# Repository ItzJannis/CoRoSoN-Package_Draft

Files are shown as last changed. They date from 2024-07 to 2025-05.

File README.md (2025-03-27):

# CoRoSoN-Package Draft
>**Co**|mponents for \
>**Ro**|bocupJunior \
>**So**|ccer \
> **N**|ewcomers \
> Project: [CoRoSoN-Kit](https://github.com/CoRoSoN-Kit/CoRoSoN-Kit) \
> Competition: [RoboCup](https://www.robocup.org) \
> Author: [BohleBots](https://www.bohlebots.de)

# Description
This project offers a draft version to the official [CoRoSoN-Kit](https://github.com/CoRoSoN-Kit/CoRoSoN-Kit) to provide the fundamental building blocks for a fully functional robot participating in the Soccer Junior division of the [RoboCup](https://www.robocup.org). \
The purpose is to allow for an newcomer friendly entry to the competition by wrapping the essential functions with easy to use APIs. Board designs are designed to be rebuild easily and affordable. \
\
Feel free to reach out to us for questions, feedback, suggestions or constructive critism! \
See you in the competition!

## Disclaimer
The software and the hardware designs are developed to the best of our knowledge to serve the intented purpose, but may still contain faults. Our software and hardware are provided "as is" and do not provide any warranty. The risk of using it and all neccessary servicing, repair and correction as well as their cost is with you.

# Makefile
Using the Arduino IDE or arduino-cli requires all source for a .ino sketch to be inside the sketch folder or inside the libaries directory of the Arduino installation. \
Therefore source files inside Software/Shared or Software/Peripheral, that are not located directly next to a .ino sketch, cause problems. \
To allow for easy compatibility of this project with Arduino the Makefile was created. \
It automates the generation of valid Arduino sketch folders, such that they can be opened in the Arduino IDE or used with arduino-cli. \
\
The Makefile does not require all source files to be inside the sketch folder, but it requires SketchName.ino to be located inside Software/SketchName/.
\
Run `make` inside the home directory of this repo to see all the options.

# Software
## Requirements
1. [Arduino](https://www.arduino.cc/)
2. [Espressif ESP32 Board Information](https://github.com/espressif/arduino-esp32)
3. [elapsedMillis](https://github.com/pfeerick/elapsedMillis/wiki)
4. [PixyI2C](https://pixycam.com/downloads-pixy1/)
5. [Pixy2I2C](https://pixycam.com/downloads-pixy2/)

## Shared
Software that is not build for a specific board but is shared across different board's software.

### CoRoSoN_Util
Providing usefull utility definitions for error handling, initializing data and better debugging. \
The `enum ERROR_CODE` provides bitflags for uniform error handling while `DEBUG_PRINT(Variable)`, `DEBUG_ERRORS(Errors)` and `DEBUG_BLOCK(Message, NumMillis)` provide easier debugging via the serial connection and the `MIN(X,Y)`, `MAX(X,Y)`, `ABS(X)`, `ARRAY_LENGTH(Arr)`, `ZEROMEM(Obj)` provide function-like macros to handle data without tedious reimplementation of often used functionalities.

### CoRoSoN_I2C
Providing a simpler, more beginner friendly interface to work with the I2C bus system used in this project. \
`I2C_Init()`, `I2C_TestConnection()`, `I2C_Write()` and `I2C_ReadBlocking()` provide all the functionality a newcomer robot for the competition needs. \
**Attention**: \
`I2C_ReadBlocking()` waits for the answers and is therefore **blocking** the execution of the program. \
Make sure that NumBytes equals the length of the passed byte array!

### CoRoSoN_Vector
Providing `class Vector` to easily compute vectorial calculations with functions and operator overloading.

### CoRoSoN_Config
This file defines the hardware configuration (namely the pins) for the software.

## Main
Software that is supposed to be used on the mainboard.
### CoRoSoN_Main
The definitions of `enum COLOR`, `enum SIDE`, `enum I2C_ADD_BTNLED_MODULE`, `enum MOTOR` and `enum DIRECTION` are used to firstly make software better readable for newcomers and secondly somehow restrict inputs to reduce buggy behavior due to occasionally wrong inputs. \
`CoRoSoN_Init()`, `CoRoSoN_SetLEDColor()`, `CoRoSoN_ButtonIsPressed()` and `CoRoSoN_SetMotor()` provide a beginner friendly API to setting the mainboard up in the `setup()` of an arduino program as well as reading and writing the mainboards pins.

## Peripheral
Software that is supposed to be used on the mainboard to make use of the peripheral devices.
### CoRoSoN_Eeprom
Providing an interface to the ESP32's eeprom which is easy to use.\
The eeprom is very usefull to save backup data about the current program state (i.e. the robot is enabled to drive) in case of a shutdown or a reset for whatever reason.\
The `struct EEPROM_DATA` can be filled with whatever you want to read / write from the eeprom.
`EEPROM_Init()`, `EEPROM_Read()` and `EEPROM_Write()` provide an easy interface that only deals with instances of `EEPROM_DATA`.

### CoRoSoN_Pixy
Providing `class Pixy` with its `Update()`, `GoalSeen()`, `OwnGoalSeen()`, `GoalDirection()` and `OwnGoalDirection()` to make use of the Pixy camera for locating the two goals on the playing field. \
In `CoRoSoN_Pixy.h` set `PIXY_VERSION` to 1 or 2 according to the version of the Pixy cam in use. \
For the directions: <0 represents left, >0 represents right

### CoRoSoN_IR-Ring
Providing `class IRRing` with its `Update()`, `BallSeen()`, `BallDirection()` and `BallDistance()` to make use of the infrared sensor ring with the firmware running on it (also provided).
For the directions: <0 represents left, >0 represents right, 0 represents front, -32 represents no ball seen
For the distance: 1...32 represents closest...furthest, 0 represents no ball seen

## IR
Software that is supposed to be used on the infrared sensor ring.
### Firmware_IR-Ring
Providing the firmware that is designed to be loaded onto the infrared sensor ring and making it ready to be used in a plug-and-play manner. \
#### Software Process / Algorithm
1. Read all physical signals
2. Remove minimum value from all sensor values (ensuring at least one is 0)
3. Use exponential moving average (EMA) for each sensor - the lower `EMA_ALPHA_PERCENTAGE`, the more the values are smoothed
4. Gaussian blur on each sensors value with its 2 neighbouring values - `BLUR_ORIGINAL_VALUE_WEIGHT_PERCENTAGE` defines the weight the middle sensor gets
5. Exaggerate differences by squaring percentage of maximum value for each sensor
6. Expand values to higher resolution by using cubic interpolation
7. Giving the sensors close to the last output direction a boost of up to 5% of their current value, to reduce fluctuations
8. Find highest value
9. Exaggerate differences by squaring percentage of maximum value for each sensor
10. Vector addition around highest value for more precise direction - `VECTOR_ADDITION_SENSOR_COUNT` defines the number of vectors involved
11. Determine distance by numeric integration
12. Compute final direction and distance with running median - `RUNNING_MEDIAN_DIRECTION_LENGTH` and `RUNNING_MEDIAN_DISTANCE_LENGTH` define the history length for the running medians

# Hardware
## Main
Contains the [KiCad](https://www.kicad.org/download/) project of the Main PCB. 

## IR-Ring
Contains the [KiCad](https://www.kicad.org/download/) project of the IR-Ring PCB. 

## 3D_Prints
Contains all the 3D printable designs as .stl files.

### CasterBall
Spherical third ground contact point to prevent the robot from falling over due to having only 2 wheels.
### Chassis_TopPlate
The main plate enclosing the chassis, also including part of the machanism to hold the battery pack.
### Dribbler_Enclosure
Holds the dribbling unit (motor and rotating silicone shell).
### Dribbler_Enclosure_EndCap
The end cap to close the enclosure of the dribbling unit.
### Dribbler_Mounting
Add-On to the top plate to mount the dribbling unit and support the IR-Ring up on top.
### Dribbler_Mounting_short
Shorter version of Dribbler_Mounting.stl in terms of height.
### Dribbler_ShellCoupling
Coupling adapter to connect the rotating shell to the motor axis.
### Dribbler_SiliconeRoller
Rotating shell of the dribbling unit, supposed to be covered with silicone.
### IR-Ring_Cover
Covers the IR-Ring PCB to reduce external ambient noise for the sensors.
### IR-Ring_Cover_Counterpart
Counterpart for the IR-Ring cover such that it is properly fixated.
### Main_Frame
Mounting frame for the Main PCB.
### Pixy_Mounting
Mounting frame for pixy camera.
### WheelCoupling
Coupling adapter to connect the wheels to the motor axis.

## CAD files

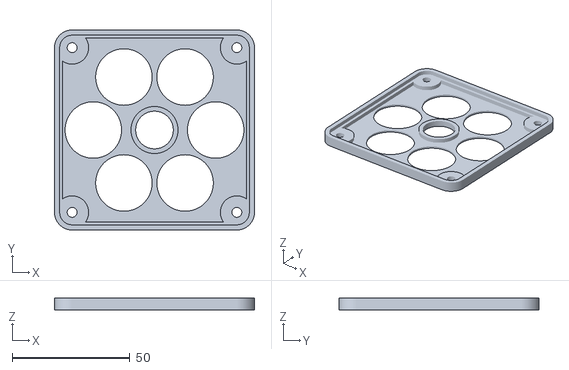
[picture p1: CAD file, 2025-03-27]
Hardware/3D_Prints/Main_Frame.stl
85.0 x 85.0 x 5.00

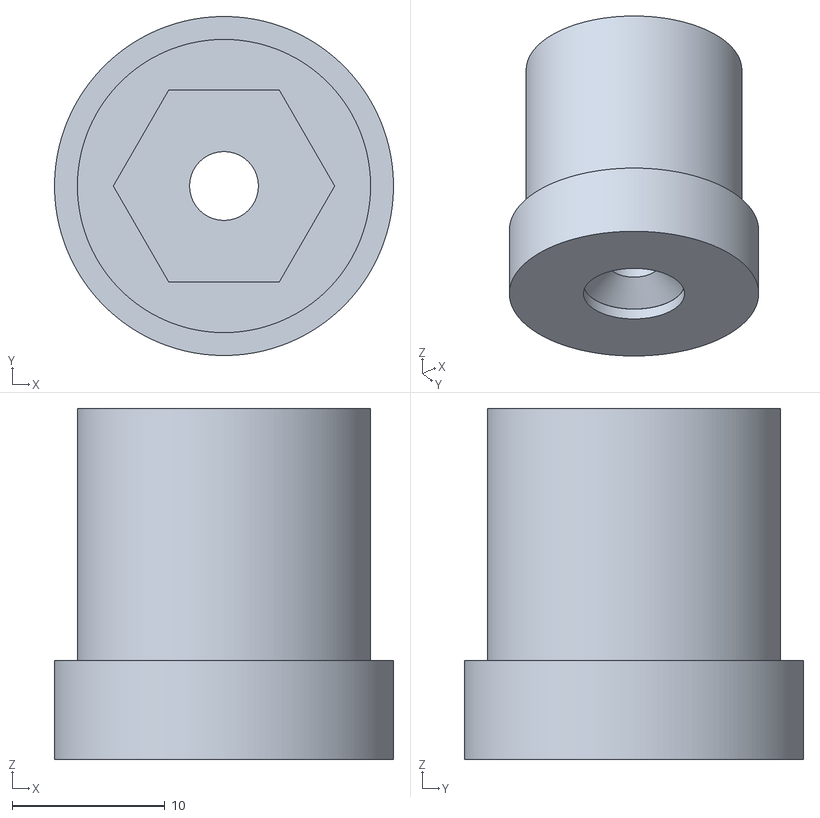
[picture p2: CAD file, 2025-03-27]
Hardware/3D_Prints/WheelCoupling.stl
22.2 x 22.2 x 23.0

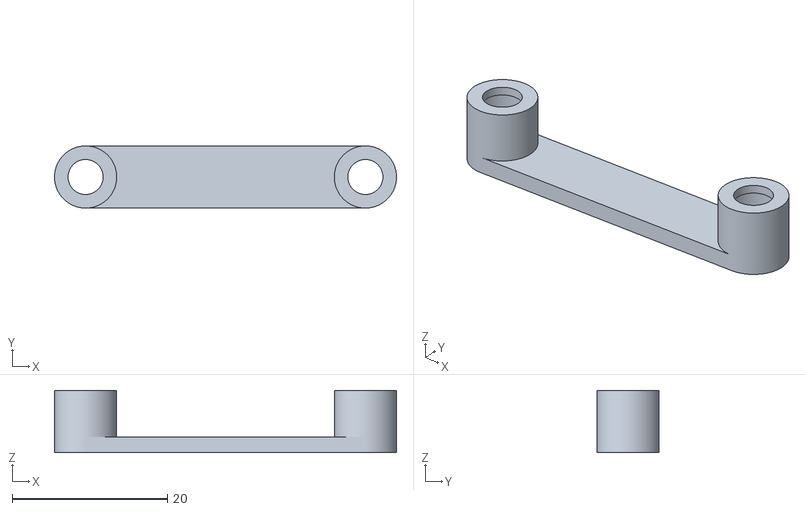
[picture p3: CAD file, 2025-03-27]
Hardware/3D_Prints/IR-Ring_Cover_Counterpart.stl
44.0 x 8.00 x 8.00

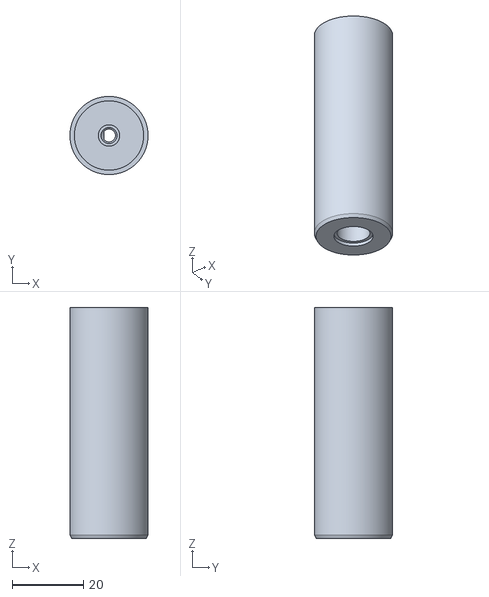
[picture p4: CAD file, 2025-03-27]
Hardware/3D_Prints/Dribbler_SiliconeRoller.stl
22.0 x 22.0 x 65.0

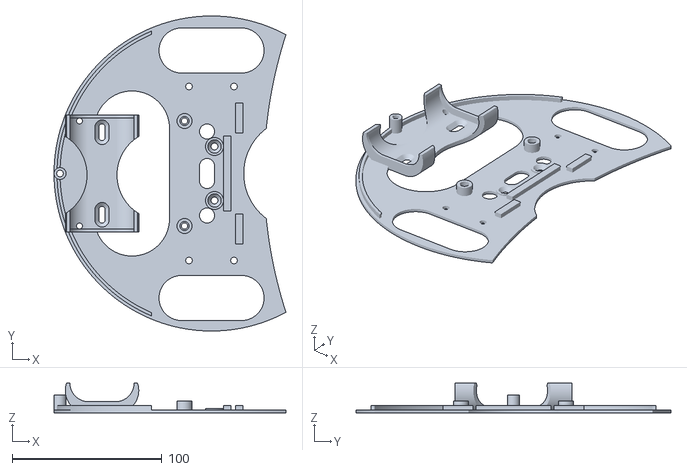
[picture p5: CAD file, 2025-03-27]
Hardware/3D_Prints/Chassis_TopPlate.stl
154.6 x 210.0 x 20.0

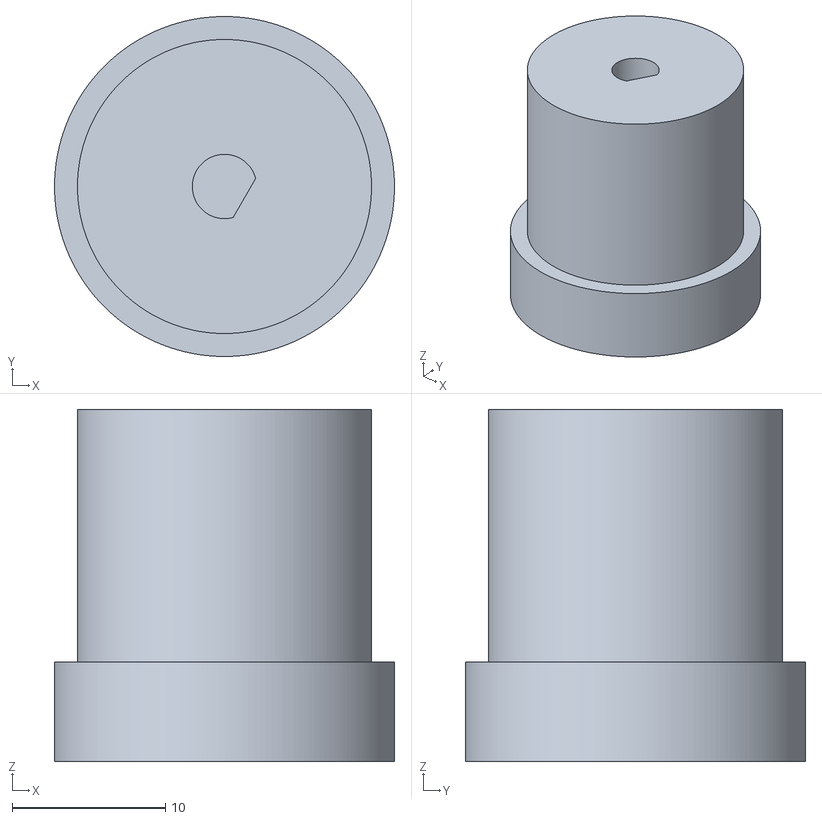
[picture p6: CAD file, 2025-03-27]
Hardware/3D_Prints/Dribbler_ShellCoupling.stl
22.2 x 22.2 x 23.0

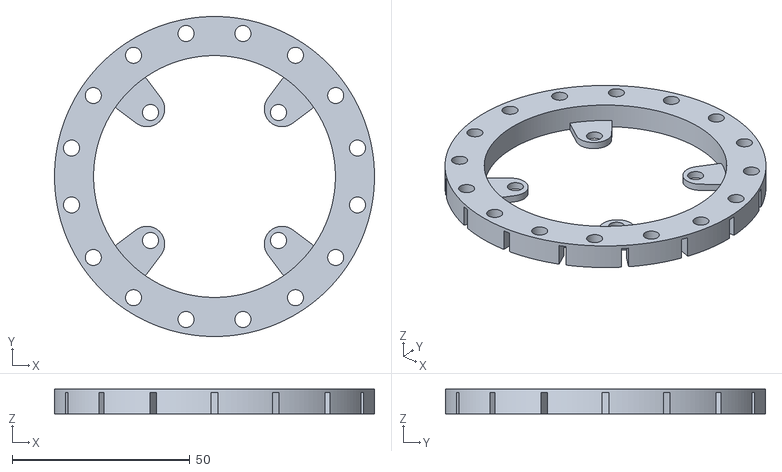
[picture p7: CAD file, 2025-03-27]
Hardware/3D_Prints/IR-Ring_Cover.stl
90.0 x 90.0 x 7.00

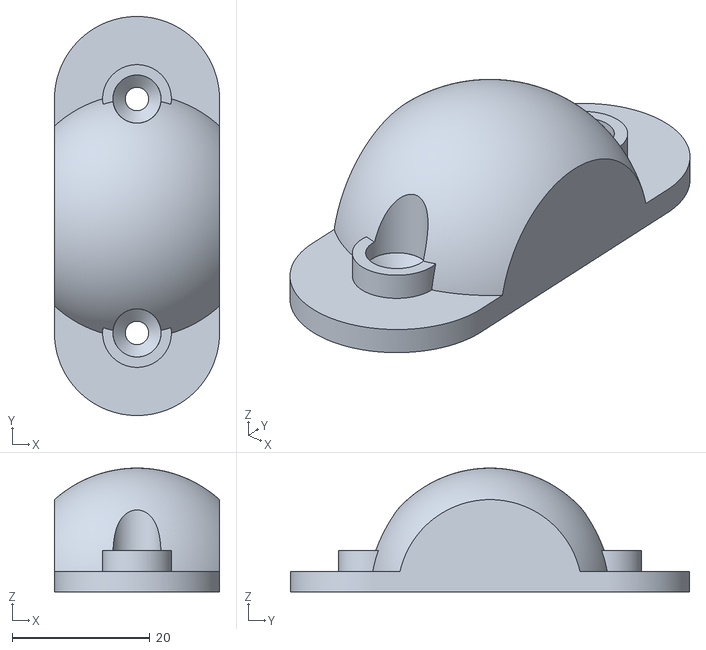
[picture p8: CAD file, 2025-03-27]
Hardware/3D_Prints/CasterBall.stl
24.0 x 58.0 x 18.0

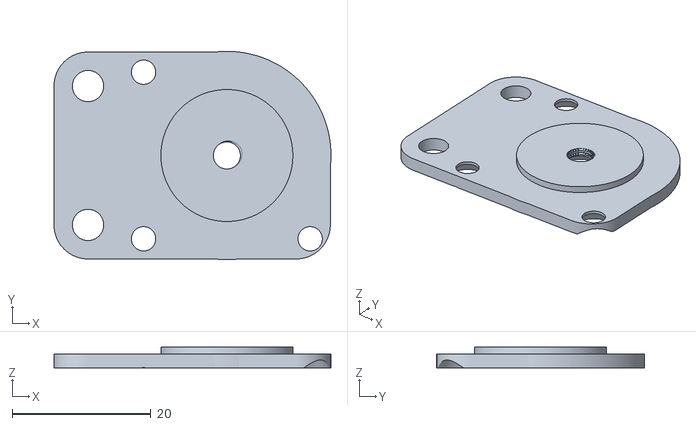
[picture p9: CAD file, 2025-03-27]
Hardware/3D_Prints/Dribbler_Enclosure_EndCap.stl
39.9 x 30.0 x 3.00

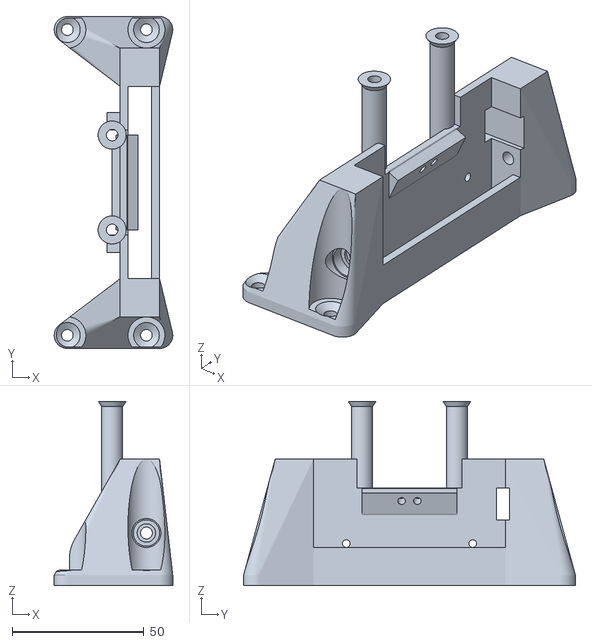
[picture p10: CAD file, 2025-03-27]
Hardware/3D_Prints/Dribbler_Mounting_short.stl
45.0 x 126.0 x 70.0

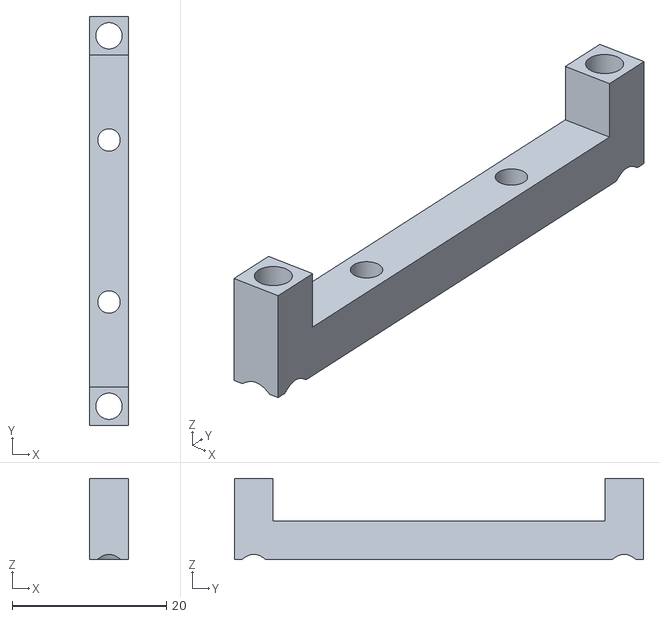
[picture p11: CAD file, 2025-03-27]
Hardware/3D_Prints/Pixy_Mounting.stl
5.00 x 53.0 x 10.5

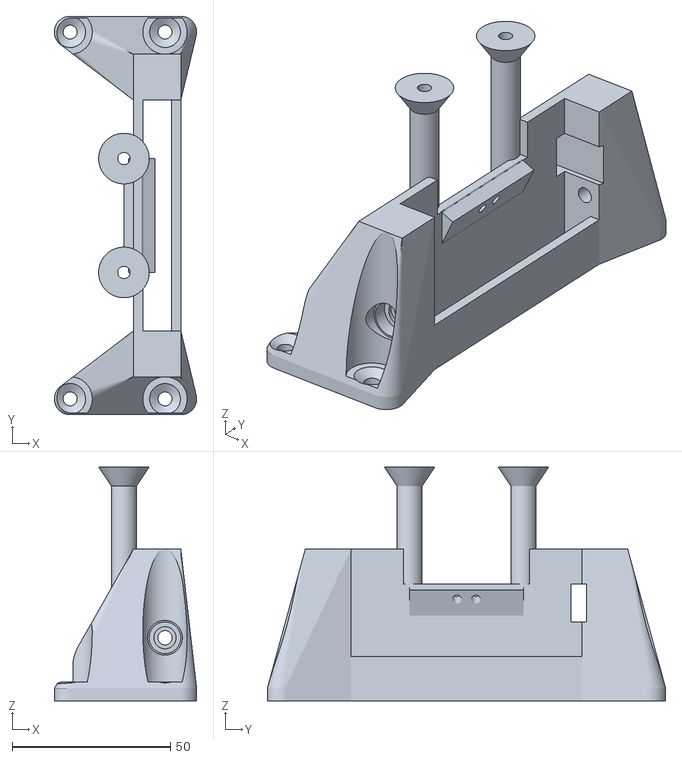
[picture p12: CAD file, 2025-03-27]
Hardware/3D_Prints/Dribbler_Mounting.stl
45.0 x 126.0 x 74.0

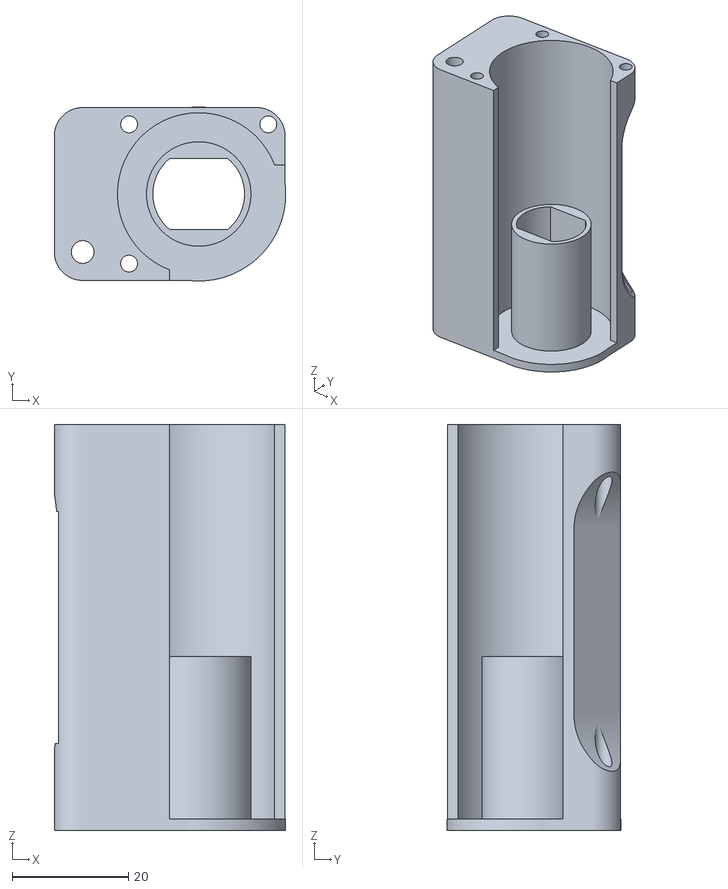
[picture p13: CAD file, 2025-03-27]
Hardware/3D_Prints/Dribbler_Enclosure.stl
39.9 x 30.0 x 70.0

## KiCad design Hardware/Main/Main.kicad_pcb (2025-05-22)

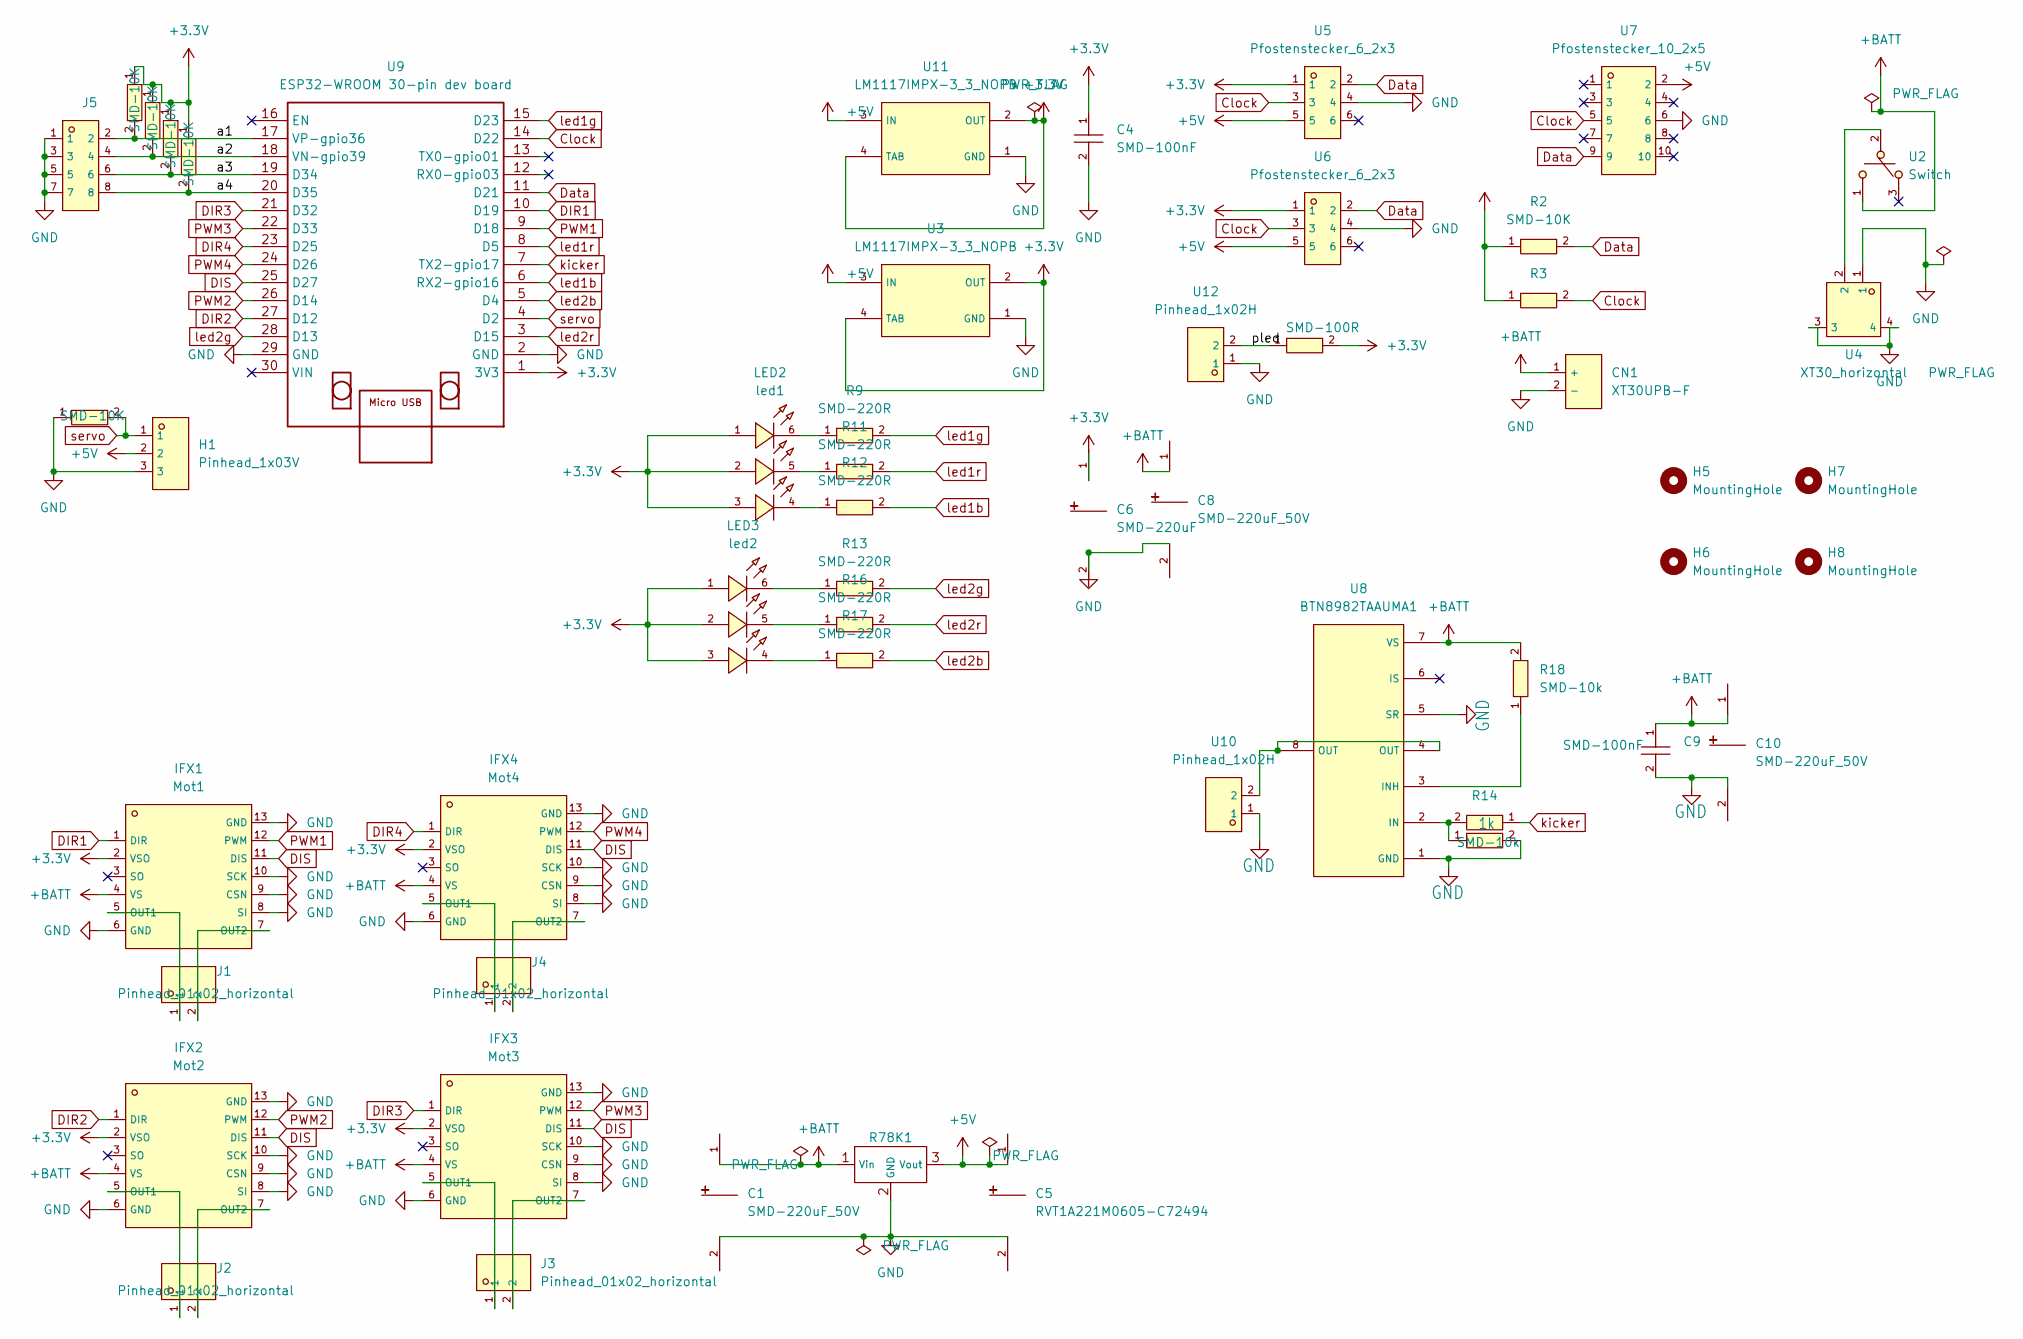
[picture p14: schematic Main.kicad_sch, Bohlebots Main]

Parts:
C1, C8, C10: SMD-220uF_50V; CAP-SMD_BD10.0-L10.3-W10.3-LS11.3-FD; LCSC C125977
C4, C9: SMD-100nF; C0603; LCSC C30926
C5: RVT1A221M0605-C72494; CAP-SMD_BD10.0-L10.3-W10.3-LS11.3-FD; LCSC C125977
C6: SMD-220uF; CAP-SMD_BD10.0-L10.3-W10.3-LS11.3-FD; LCSC C125977
CN1: XT30UPB-F; CONN-TH_XT30UPB-F; LCSC C108769
H1: Pinhead_1x03V; HDR-TH_3P-P2.54-V-M-1; LCSC C7501261
H5, H6, H7, H8: MountingHole; MountingHole_4.3mm_M4
IFX1: Mot1; SO-12_L6.4-W7.5-P1.00-LS10.3-BL-EP; LCSC C112633
IFX2: Mot2; SO-12_L6.4-W7.5-P1.00-LS10.3-BL-EP; LCSC C112633
IFX3: Mot3; SO-12_L6.4-W7.5-P1.00-LS10.3-BL-EP; LCSC C112633
IFX4: Mot4; SO-12_L6.4-W7.5-P1.00-LS10.3-BL-EP; LCSC C112633
J1, J2, J3, J4: Pinhead_01x02_horizontal; HDR-TH_2P-P2.54-H-M-W10.4; LCSC C492410
J5: Conn_02x04_Row_Letter_First; HDR-TH_8P-P2.54-H-M-R2-C4-S2.54; LCSC C706885
LED2: led1; LED-SMD_6P-L5.0-W5.0-TL_TC5050RGBF08; LCSC C784540
LED3: led2; LED-SMD_6P-L5.0-W5.0-TL_TC5050RGBF08; LCSC C784540
R2, R3, R5, R6, R7, R10, R15: SMD-10K; R0603; LCSC C25804
R8: SMD-100R; R0603; LCSC C22775
R9, R11, R12, R13, R16, R17: SMD-220R; R0603; LCSC C217883
R14, R18: SMD-10k; R0603; LCSC C25804
R23: 1k; R0603; LCSC C22548
R78K1: R785K
U2: Switch; SW-TH_MT-0-103-A101-M200-RS; LCSC C1788498
U3, U11: LM1117IMPX-3_3_NOPB; SOT-223_L6.5-W3.5-P2.30-LS7.0-BR; LCSC C23984
U4: XT30_horizontal; CONN-TH_XT30PW-M; LCSC C431092
U5, U6: Pfostenstecker_6_2x3; HDR-TH_6P-P2.54-V-F-R2-C3-S2.54-4; LCSC C5372863
U7: Pfostenstecker_10_2x5; HDR-TH_10P-P2.54-V-F-R2-C5-S2.54-5; LCSC C5372865
U8: BTN8982TAAUMA1; TO-263-7_L10.2-W10.4-P1.27-LS14.4-TL; LCSC C74175
U9: ESP32-WROOM 30-pin dev board; MODULE_ESP32_DEVKIT_V1
U10, U12: Pinhead_1x02H; HDR-TH_2P-P2.54-H-M-W10.4; LCSC C492410

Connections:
+3.3V: C4.1, C6.1, IFX1.2 (VSO), IFX2.2 (VSO), IFX3.2 (VSO), IFX4.2 (VSO), LED2.1 (+), LED2.2 (+), LED2.3 (+), LED3.1 (+), LED3.2 (+), LED3.3 (+), R2.1, R3.1, R5.1, R6.1, R7.1, R8.2, R10.1, U3.2 (OUT), U3.4 (TAB), U5.1, U6.1, U9.1 (3V3), U11.2 (OUT), U11.4 (TAB)
+5V: C5.1, H1.2, R78K1.3 (Vout), U3.3 (IN), U5.5, U6.5, U7.2, U11.3 (IN)
+BATT: C1.1, C8.1, C9.1, C10.1, CN1.1 (+), IFX1.4 (VS), IFX2.4 (VS), IFX3.4 (VS), IFX4.4 (VS), R18.2, R78K1.1 (Vin), U2.1, U8.7 (VS)
/a1: J5.2, R5.2, U9.17 (VP-gpio36)
/a2: J5.4, R6.2, U9.18 (VN-gpio39)
/a3: J5.6, R7.2, U9.19 (D34)
/a4: J5.8, R10.2, U9.20 (D35)
/pled: R8.1, U12.2
Clock: R3.2, U5.3, U6.3, U7.5, U9.14 (D22)
DIR1: IFX1.1 (DIR), U9.10 (D19)
DIR2: IFX2.1 (DIR), U9.27 (D12)
DIR3: IFX3.1 (DIR), U9.21 (D32)
DIR4: IFX4.1 (DIR), U9.23 (D25)
DIS: IFX1.11 (DIS), IFX2.11 (DIS), IFX3.11 (DIS), IFX4.11 (DIS), U9.25 (D27)
Data: R2.2, U5.2, U6.2, U7.9, U9.11 (D21)
GND: C1.2, C4.2, C5.2, C6.2, C8.2, C9.2, C10.2, CN1.2 (-), H1.3, IFX1.6 (GND), IFX1.8 (SI), IFX1.9 (CSN), IFX1.10 (SCK), IFX1.13 (GND), IFX2.6 (GND), IFX2.8 (SI), IFX2.9 (CSN), IFX2.10 (SCK), IFX2.13 (GND), IFX3.6 (GND), IFX3.8 (SI), IFX3.9 (CSN), IFX3.10 (SCK), IFX3.13 (GND), IFX4.6 (GND), IFX4.8 (SI), IFX4.9 (CSN), IFX4.10 (SCK), IFX4.13 (GND), J5.1, J5.3, J5.5, J5.7, R14.2, R15.1, R78K1.2 (GND), U3.1 (GND), U4.1, U4.3, U4.4, U5.4, U6.4, U7.6, U8.1 (GND), U8.5 (SR), U9.2 (GND), U9.29 (GND), U10.1, U11.1 (GND), U12.1
unnamed: IFX1.5 (OUT1), J1.1
unnamed: IFX1.7 (OUT2), J1.2
unnamed: IFX2.5 (OUT1), J2.1
unnamed: IFX2.7 (OUT2), J2.2
unnamed: IFX3.5 (OUT1), J3.1
unnamed: IFX3.7 (OUT2), J3.2
unnamed: IFX4.5 (OUT1), J4.1
unnamed: IFX4.7 (OUT2), J4.2
unnamed: LED2.4 (-), R12.1
unnamed: LED2.5 (-), R11.1
unnamed: LED2.6 (-), R9.1
unnamed: LED3.4 (-), R17.1
unnamed: LED3.5 (-), R16.1
unnamed: LED3.6 (-), R13.1
unnamed: U2.2, U4.2
unnamed: R14.1, R23.2, U8.2 (IN)
unnamed: R18.1, U8.3 (INH)
unnamed: U8.4 (OUT), U8.8 (OUT), U10.2
PWM1: IFX1.12 (PWM), U9.9 (D18)
PWM2: IFX2.12 (PWM), U9.26 (D14)
PWM3: IFX3.12 (PWM), U9.22 (D33)
PWM4: IFX4.12 (PWM), U9.24 (D26)
kicker: R23.1, U9.7 (TX2-gpio17)
led1b: R12.2, U9.6 (RX2-gpio16)
led1g: R9.2, U9.15 (D23)
led1r: R11.2, U9.8 (D5)
led2b: R17.2, U9.5 (D4)
led2g: R13.2, U9.28 (D13)
led2r: R16.2, U9.3 (D15)
servo: H1.1, R15.2, U9.4 (D2)

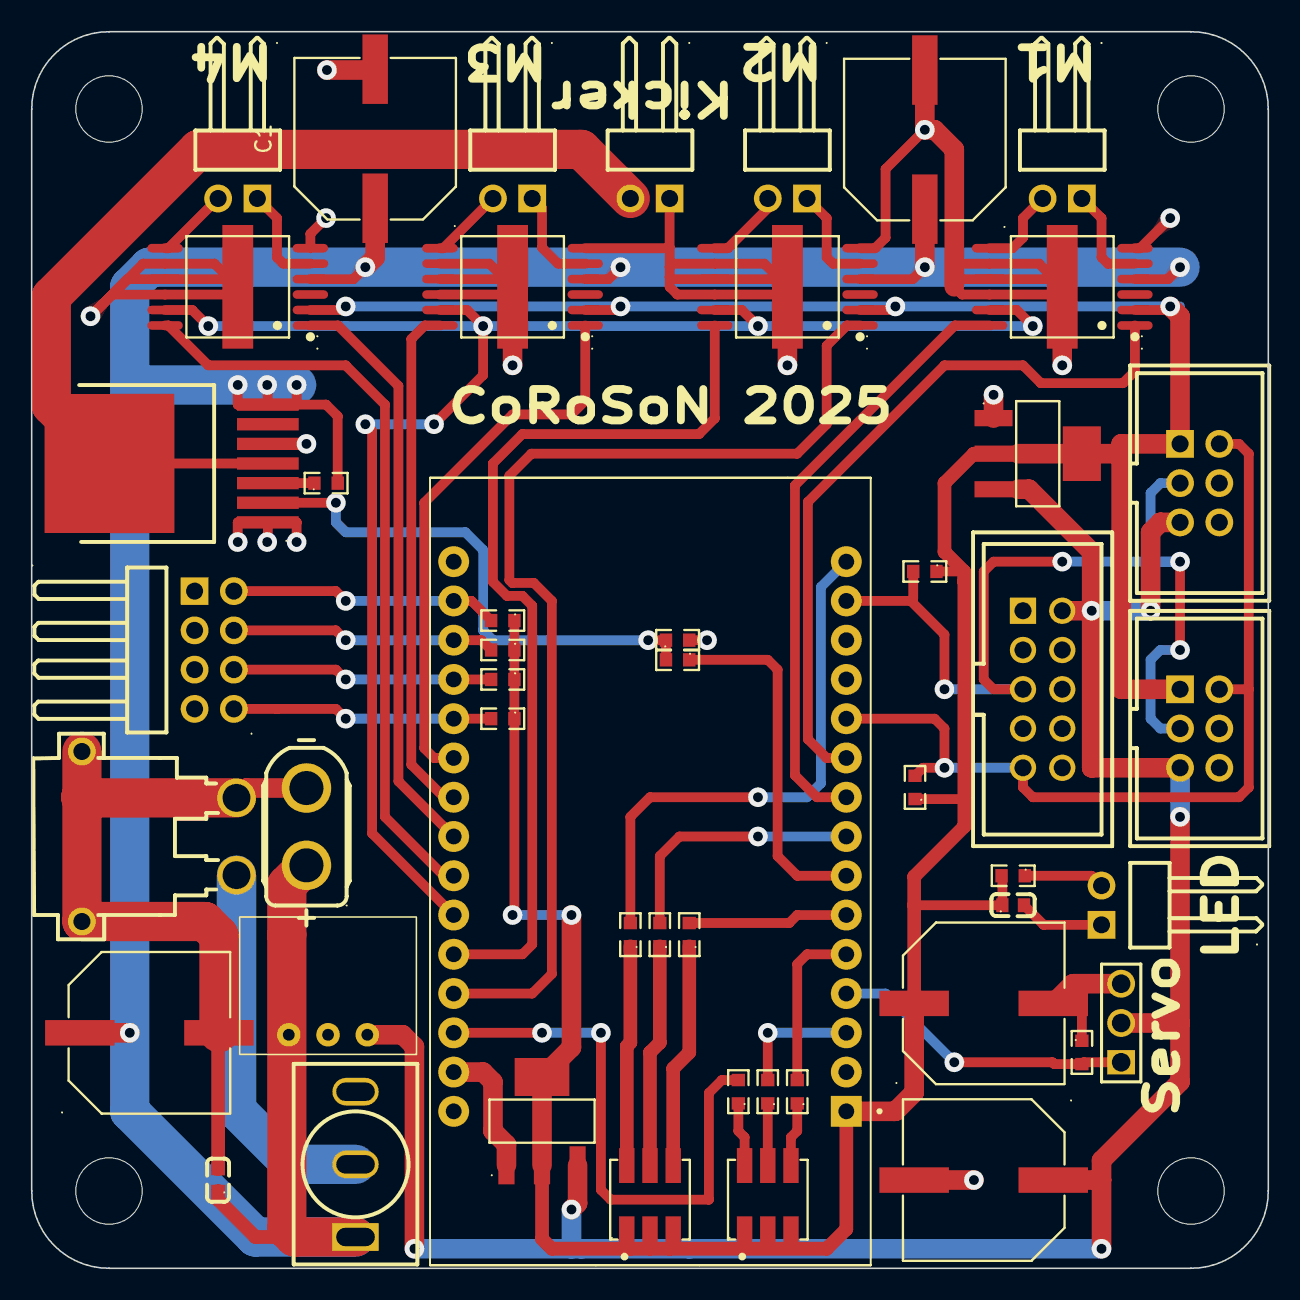
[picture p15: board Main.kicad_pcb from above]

Board: 2 copper layers, 80.0 x 80.0 mm, 53 parts (0 on the bottom side), 46 nets.

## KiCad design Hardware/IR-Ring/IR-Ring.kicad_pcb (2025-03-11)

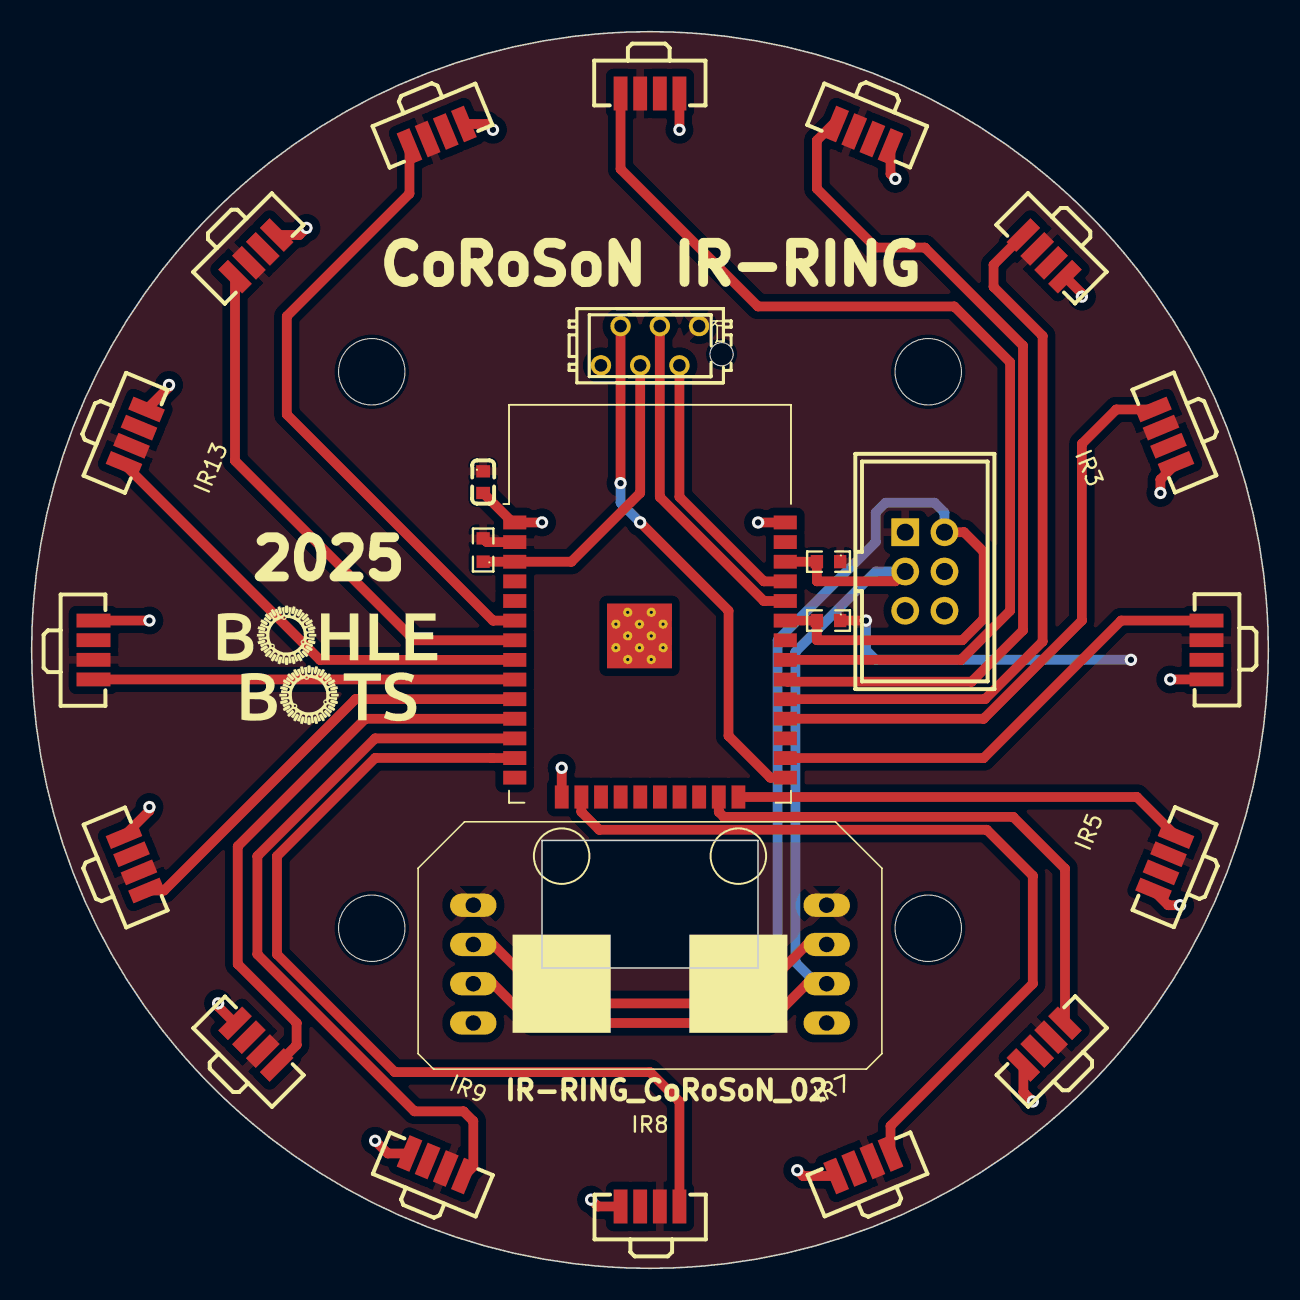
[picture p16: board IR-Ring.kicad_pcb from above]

Board: 2 copper layers, 80.0 x 80.0 mm, 28 parts (0 on the bottom side), 24 nets.

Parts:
C2: SMD-1uF; C0603
H1, H2, H3, H4: MountingHole; MountingHole_4.3mm_M4
IR0, IR1, IR2, IR3, IR4, IR5, IR6, IR7, IR8, IR9, IR10, IR11, IR12, IR13, IR14, IR15: TSSP6038TR; SENSOR-SMD_TSSP6038TR
R1, R2, R3: SMD-10k; R0603
Taster_LED1: TASTER_LED
U1: ESP32-WROOM-32; ESP32-WROOM-32-small
U2: Pfostenstecker_6_2x3; HDR-TH_6P-P2.54-V-F-R2-C3-S2.54-4
X1: MICROMATCH-6

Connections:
+3.3V: C2.1, IR0.3 (VS), IR1.3 (VS), IR2.3 (VS), IR3.3 (VS), IR4.3 (VS), IR5.3 (VS), IR6.3 (VS), IR7.3 (VS), IR8.3 (VS), IR9.3 (VS), IR10.3 (VS), IR11.3 (VS), IR12.3 (VS), IR13.3 (VS), IR14.3 (VS), IR15.3 (VS), R1.2, R2.1, R3.1, Taster_LED1.1 (v+), Taster_LED1.8, U1.2 (VDD), U2.1, X1.1
Boot: U1.25 (IO0), X1.5
Clock: R3.2, Taster_LED1.3 (Clock), Taster_LED1.6, U1.36 (IO22), U2.3
D1: IR0.4 (OUT), U1.31 (IO19)
D2: IR1.4 (OUT), U1.30 (IO18)
D3: IR2.4 (OUT), U1.29 (IO5)
D4: IR3.4 (OUT), U1.28 (IO17)
D5: IR12.4 (OUT), U1.9 (IO33)
D6: IR13.4 (OUT), U1.8 (IO32)
D7: IR14.4 (OUT), U1.7 (IO35)
D8: IR15.4 (OUT), U1.6 (IO34)
D9: IR4.4 (OUT), U1.26 (IO4)
D10: IR5.4 (OUT), U1.24 (IO2)
D11: IR6.4 (OUT), U1.23 (IO15)
D12: IR7.4 (OUT), U1.16 (IO13)
D13: IR8.4 (OUT), U1.13 (IO14)
D14: IR9.4 (OUT), U1.12 (IO27)
D15: IR10.4 (OUT), U1.11 (IO26)
D16: IR11.4 (OUT), U1.10 (IO25)
Data: R2.2, Taster_LED1.2 (Data), Taster_LED1.7, U1.33 (IO21), U2.2
EN: R1.1, U1.3 (EN), X1.4
GND: C2.2, IR0.1 (GND), IR1.1 (GND), IR2.1 (GND), IR3.1 (GND), IR4.1 (GND), IR5.1 (GND), IR6.1 (GND), IR7.1 (GND), IR8.1 (GND), IR9.1 (GND), IR10.1 (GND), IR11.1 (GND), IR12.1 (GND), IR13.1 (GND), IR14.1 (GND), IR15.1 (GND), Taster_LED1.4 (GND), Taster_LED1.5, U1.1 (GND), U1.15 (GND), U1.38 (GND), U1.39 (GND), U2.4, X1.6
RX: U1.34 (RXD0/IO3), X1.3
TX: U1.35 (TXD0/IO1), X1.2

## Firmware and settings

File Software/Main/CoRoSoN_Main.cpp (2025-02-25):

// -------------------------------------------------------------------
/*********************************************************************
* 
* !    LICENSE
*         GNU GPL 3.0
*
*********************************************************************/
// -------------------------------------------------------------------
/*********************************************************************
* 
* *     CoRoSoN
* *       Co|mponents for 
* *       Ro|bocupJunior
* *       So|ccer
* *        N|ewcomers
*
* *    Project:     https://github.com/CoRoSoN-Kit/CoRoSoN-Kit
* *    Competition: https://www.robocup.org/
*
* *    Created by BohleBots:
* *       https://www.bohlebots.de
* *       info@bohlebots.de
* 
*********************************************************************/
// -------------------------------------------------------------------
// File:    CoRoSoN.cpp
// Purpose: Implementations for CoRoSoN.h
// -------------------------------------------------------------------
/*********************************************************************
* 
*  Dependencies
*
*********************************************************************/
#include "CoRoSoN_Main.h"
/*********************************************************************
* 
*  Implementations
*
*********************************************************************/
static byte _LEDModule1Left  = 0;
static byte _LEDModule1Right = 0;
static byte _LEDModule2Left  = 0;
static byte _LEDModule2Right = 0;

ERRORS CoRoSoN_Init() {
  ERRORS r;
  int    i;
  
  r = OKAY;
  i = 0;
  //
  // Serial Monitor
  //
  Serial.begin(115200);
  //
  // I2C
  //
  r |= I2C_Init(I2C_SDA, I2C_SCL);
  if(r) {
    r |= (CONNECT_FAILED | ERROR_IGNORED);
    DEBUG_ERRORS(r);
    DEBUG_BLOCK("I2C Init failed", 1000);
  }
  //
  // Button and LED modules
  //
  r |= I2C_TestConnection(I2C_MODULE_1);
  if(r) {
    r |= (CONNECT_FAILED | ERROR_IGNORED);
    DEBUG_ERRORS(r);
  }
  r |= I2C_TestConnection(I2C_MODULE_2);
  if(r) {
    r |= (CONNECT_FAILED | ERROR_IGNORED);
    DEBUG_ERRORS(r);
  }
  //
  // Pins
  //
  // Motors
  pinMode(MOTOR_DIS, OUTPUT); digitalWrite(MOTOR_DIS, LOW);
  pinMode(MOTOR_1_DIR, OUTPUT);
  pinMode(MOTOR_2_DIR, OUTPUT);
  pinMode(MOTOR_3_DIR, OUTPUT);
  pinMode(MOTOR_4_DIR, OUTPUT);
  ledcAttach(MOTOR_1_PWM, 1000, 8);
  ledcAttach(MOTOR_2_PWM, 1000, 8);
  ledcAttach(MOTOR_3_PWM, 1000, 8);
  ledcAttach(MOTOR_4_PWM, 1000, 8);
  ledcWrite(MOTOR_1_PWM, 0);
  ledcWrite(MOTOR_2_PWM, 0);
  ledcWrite(MOTOR_3_PWM, 0);
  ledcWrite(MOTOR_4_PWM, 0);
  // Analog
  pinMode(ANALOG_IN_1, INPUT);
  pinMode(ANALOG_IN_2, INPUT);
  pinMode(ANALOG_IN_3, INPUT);
  pinMode(ANALOG_IN_4, INPUT);
  // LEDs
  pinMode(ONBOARD_LED_LEFT_R , OUTPUT); digitalWrite(ONBOARD_LED_LEFT_R , HIGH);
  pinMode(ONBOARD_LED_LEFT_G , OUTPUT); digitalWrite(ONBOARD_LED_LEFT_G , HIGH);
  pinMode(ONBOARD_LED_LEFT_B , OUTPUT); digitalWrite(ONBOARD_LED_LEFT_B , HIGH);
  pinMode(ONBOARD_LED_RIGHT_R, OUTPUT); digitalWrite(ONBOARD_LED_RIGHT_R, HIGH);
  pinMode(ONBOARD_LED_RIGHT_G, OUTPUT); digitalWrite(ONBOARD_LED_RIGHT_G, HIGH);
  pinMode(ONBOARD_LED_RIGHT_B, OUTPUT); digitalWrite(ONBOARD_LED_RIGHT_B, HIGH);
  // Digital
  pinMode(DIGITAL_OUT_1, OUTPUT); digitalWrite(DIGITAL_OUT_1, LOW);
  pinMode(DIGITAL_OUT_2, OUTPUT); digitalWrite(DIGITAL_OUT_2, LOW);
  return r;
}

ERRORS CoRoSoN_SetBoardLEDColor(SIDE Side, COLOR Color) {
  switch(Side) {
    case LEFT: 
      digitalWrite(ONBOARD_LED_LEFT_R , !(Color & (1 << 0)));
      digitalWrite(ONBOARD_LED_LEFT_G , !(Color & (1 << 1)));
      digitalWrite(ONBOARD_LED_LEFT_B , !(Color & (1 << 2)));
      break;
    case RIGHT: 
      digitalWrite(ONBOARD_LED_RIGHT_R , !(Color & (1 << 0)));
      digitalWrite(ONBOARD_LED_RIGHT_G , !(Color & (1 << 1)));
      digitalWrite(ONBOARD_LED_RIGHT_B , !(Color & (1 << 2)));
      break;
  }
  return OKAY;
}

ERRORS CoRoSoN_SetI2CLEDColor(I2C_ADD_BTNLED_MODULE AddModule, SIDE Side, COLOR Color) {
  ERRORS r;
  byte   bColor;
  byte   aMessage[1];

  r = OKAY;
  bColor = (byte)Color;
  ZEROMEM(aMessage);
  switch(AddModule) {
    case I2C_MODULE_1: 
      switch(Side) {
        case LEFT: 
          _LEDModule1Left = bColor * 2; 
          break;
        case RIGHT: bColor *= 16; 
          if(bColor > 63) {
            bColor += 64;
           } 
           _LEDModule1Right = bColor; 
           break;
      }
      aMessage[0] = 255 - _LEDModule1Left - _LEDModule1Right; 
      break;
    case I2C_MODULE_2: 
      switch(Side) {
        case LEFT: 
          _LEDModule2Left  = bColor * 2; 
          break;
        case RIGHT: bColor *= 16; 
          if(bColor > 63) {
            bColor += 64;
           } 
           _LEDModule2Right = bColor; 
           break;
      }
      aMessage[0] = 255 - _LEDModule2Left - _LEDModule2Right; 
      break;
  }
  r |= I2C_Write(AddModule, aMessage, ARRAY_LENGTH(aMessage));
  if(r) {
    r |= CONNECT_FAILED;
    DEBUG_ERRORS(r);
  }
  return r;
}

bool CoRoSoN_ButtonIsPressed(I2C_ADD_BTNLED_MODULE AddModule, SIDE Side) {
  bool   IsPressed;
  ERRORS r;
  byte   aAnswer[1];

  IsPressed = false;
  r = OKAY;
  ZEROMEM(aAnswer);
  r |= I2C_ReadBlocking(AddModule, aAnswer, 1);
  if(r) {
    r |= ERROR_BREAK_OUT;
    DEBUG_ERRORS(r);
    return false;
  }
  switch(Side) {
    case LEFT : IsPressed = ((~aAnswer[0]) & (1 << 0)); break; // left  btn presed =>  1-bit is 0
    case RIGHT: IsPressed = ((~aAnswer[0]) & (1 << 6)); break; // right btn presed => 64-bit is 0
  }
  return IsPressed;
}

ERRORS CoRoSoN_SetMotor(MOTOR Motor, DIRECTION Direction, unsigned int SpeedPercentage) {
  ERRORS r;

  r = OKAY;
  if(SpeedPercentage > 100) {
    r |=  INVALID_PARAMETER | ERROR_HANDLED;
    DEBUG_ERRORS(r);
    DEBUG_PRINT(SpeedPercentage);
    SpeedPercentage = 100;
  }
  switch(Motor) {
    case MOTOR_1: digitalWrite(MOTOR_1_DIR, Direction); ledcWrite(MOTOR_1_PWM, (SpeedPercentage * 255) / 100); break;
    case MOTOR_2: digitalWrite(MOTOR_2_DIR, Direction); ledcWrite(MOTOR_2_PWM, (SpeedPercentage * 255) / 100); break;
    case MOTOR_3: digitalWrite(MOTOR_3_DIR, Direction); ledcWrite(MOTOR_3_PWM, (SpeedPercentage * 255) / 100); break;
    case MOTOR_4: digitalWrite(MOTOR_4_DIR, Direction); ledcWrite(MOTOR_4_PWM, (SpeedPercentage * 255) / 100); break;
  }
  return r;
}

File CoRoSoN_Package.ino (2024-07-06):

#include "CoRoSoN.h"

void setup() {
  Serial.begin(115200);
  //DEBUG_BLOCK("test", 1000); // uncomment this line to block the processor with periodic printing
}

void loop() {
  ERRORS Errors = OKAY; // start with everything okay
  
  DEBUG_PRINT(Errors);
  // create bitmap to show which errors occured
  Errors = ERROR_BREAK_OUT | PROCESS_RUNNING | INVALID_CONFIG | CONNECT_FAILED;
  // print errors because one occured
  DEBUG_PRINT(Errors);
  DEBUG_ERRORS(Errors);
  // block cpu for ever with "test" printed every 2 seconds
  DEBUG_BLOCK("test", 2000);
}

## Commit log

2023-09-26 Package now arduino compatible
2023-10-03 ArduinoFile uses CoRoSoN_Util
2023-10-15 Implemented I2C module
2023-10-15 Compass uses I2C module
2023-10-15 I2C cleanup
2023-12-13 ERRORS as typedef instead of define
    [CoRoSoN_Util.h]
2024-07-03 Last bugfixes to allow testing
    [CoRoSoN.cpp, Firmware_IR-Ring.h]
2024-07-03 small bugfix: "ERROR" => "ERRORS"
    [Firmware_IR-Ring.h]
2024-07-06 Fixed compiler errors and warnings
    [CoRoSoN_Util.h, Firmware_IR-Ring.h]
2024-07-07 Bugfix: TotalSum was not set
    [Firmware_IR-Ring.h]
2024-08-30 Bugfix in macro definition
    [CoRoSoN_Util.h]
2024-09-17 Split config of CoRoSoN.h into CoRoSoN_Config.h to seperate it from main board code for ir firmware
2024-09-30 Changed defines to please arduino
2024-12-13 Bitshifts for ERROR enum instead of binary numbers
    [CoRoSoN_Util.h]
2024-12-31 Pins were shifted by 1 to the left and therefore wrong. Fixed.
    [Firmware_IR-Ring.h]
2025-01-17 IRRing class constructor no longer tests I2C to allow call before setup()
2025-01-20 Modified default defines in IR Firmware to smaller PCB
2025-01-26 EMA for each sensor + running median for overall direction and distance
2025-02-25 I2C fixed - demo build for LEDs, buttons and motor working
    [CoRoSoN_Main.cpp, CoRoSoN_Util.h]
2025-02-27 Added Subfolder for generated arduino sketches to .gitignore
2025-02-28 Added Makefile for easy use with Arduino IDE and arduino-cli.
2025-03-06 IR: Fixed underflow of _BallDir
    [CoRoSoN_Util.h]
2025-03-11 Added KiCad projects of Main and IR-Ring PCB to repo.
    [IR-Ring.kicad_pcb, IR-Ring.kicad_sch, Main.kicad_pcb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]
2025-03-27 Added 3D print designs to the Hardware folder.
    [CasterBall.stl, Chassis_TopPlate.stl, Dribbler_Enclosure.stl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]
2025-05-22 Updated pcb design of main board
    [Main.kicad_pcb]
